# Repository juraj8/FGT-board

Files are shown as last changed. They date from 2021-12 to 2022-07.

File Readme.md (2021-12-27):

# FGT





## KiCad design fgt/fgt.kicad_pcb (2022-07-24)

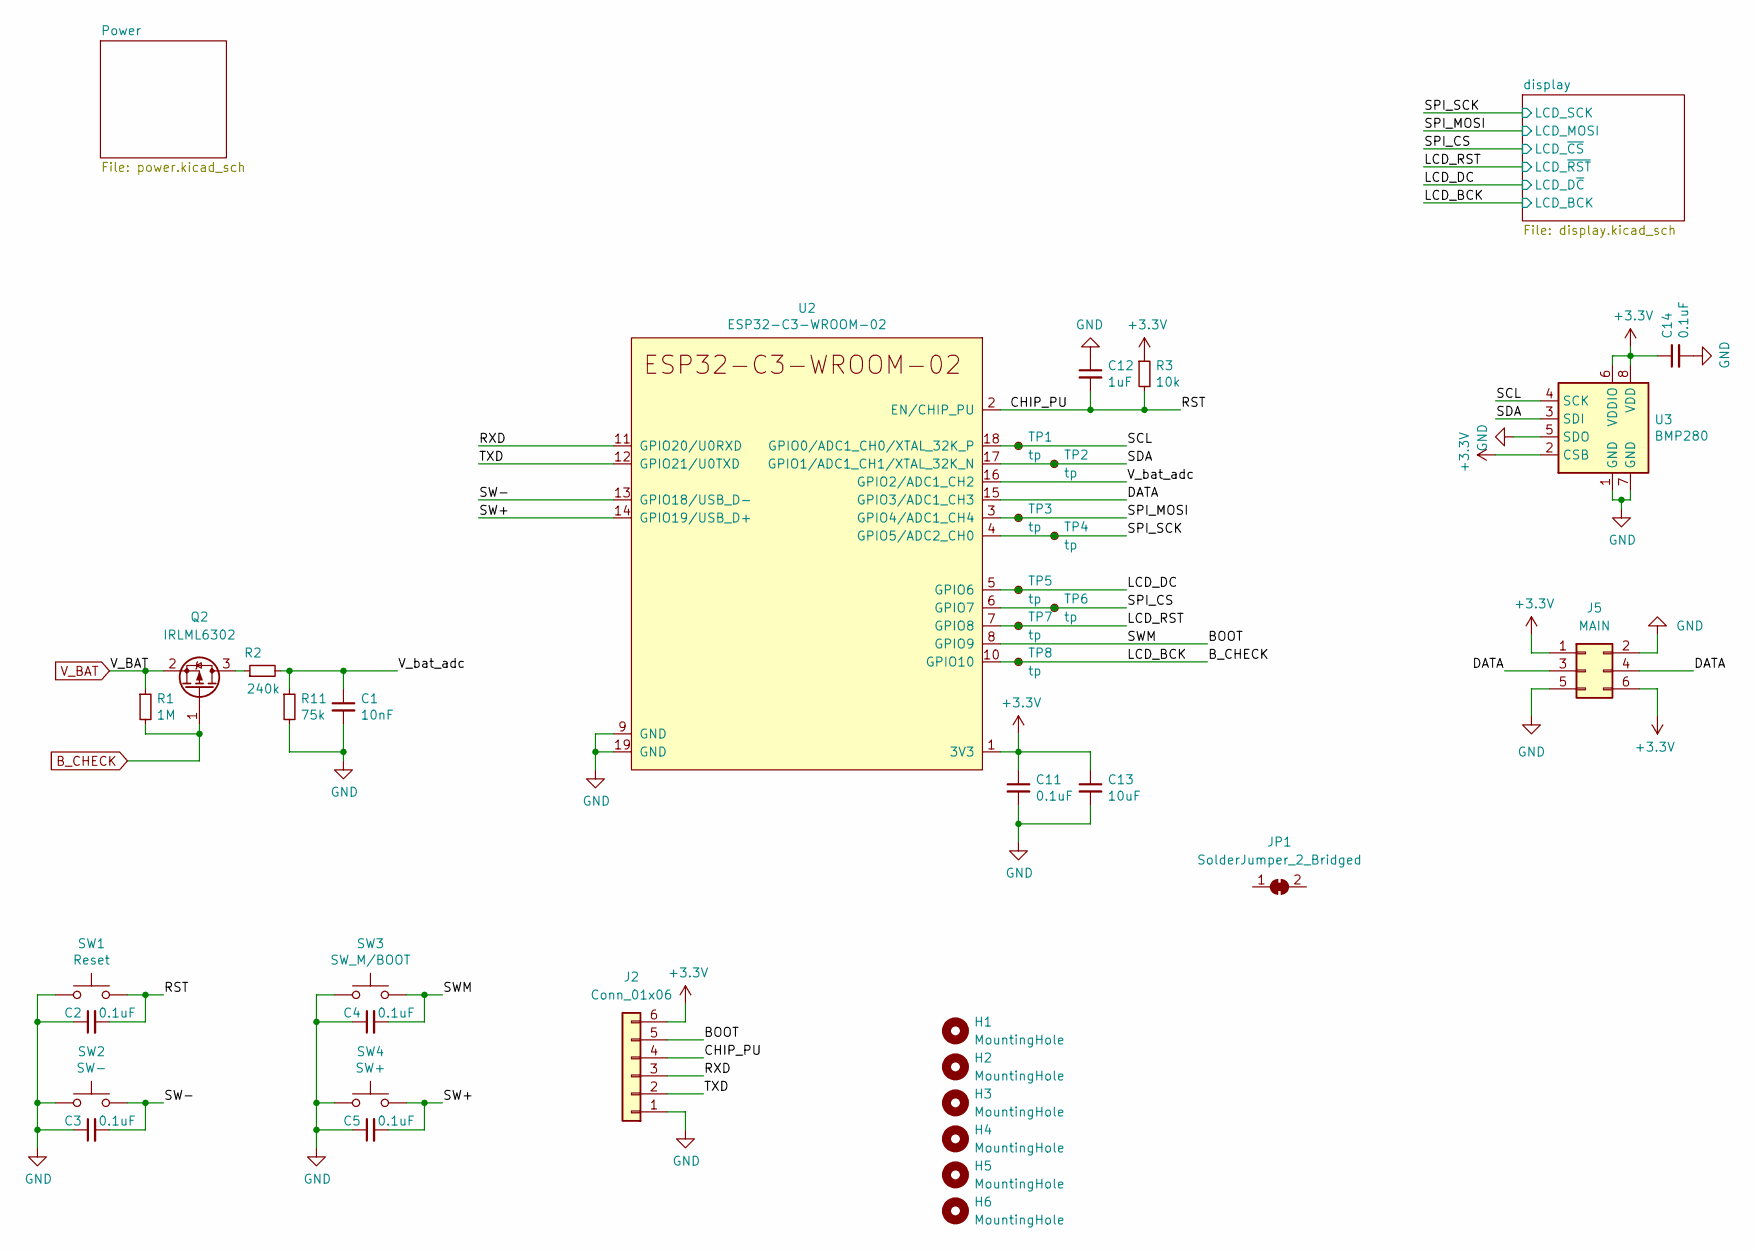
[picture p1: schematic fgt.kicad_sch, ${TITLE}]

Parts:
C1: 10nF; C_0805_2012Metric
C2, C3, C4, C5: 0.1uF; C_0805_2012Metric
C11, C14: 0.1uF; C_0603_1608Metric
C12: 1uF; C_0603_1608Metric
C13: 10uF; C_0805_2012Metric
H1, H2, H3, H4, H5, H6: MountingHole; MountingHole_3.2mm_M3_DIN965
J2: Conn_01x06; PinHeader_1x06_P2.54mm_Vertical
J5: MAIN; IDC-Header_2x03_P2.54mm_Vertical
JP1: SolderJumper_2_Bridged; SolderJumper-2_P1.3mm_Bridged_RoundedPad1.0x1.5mm
Q2: IRLML6302; SOT-23
R1: 1M; R_0805_2012Metric
R2: 240k; R_0805_2012Metric
R3: 10k; R_0805_2012Metric
R11: 75k; R_0805_2012Metric
SW1: Reset; SW_SPST_SKQG_WithStem
SW2: SW-; SW_SPST_SKQG_WithStem
SW3: SW_M/BOOT; SW_SPST_SKQG_WithStem
SW4: SW+; SW_SPST_SKQG_WithStem
TP1, TP2, TP3, TP4, TP5, TP6, TP7, TP8: tp; TestPoint_Pad_D1.0mm
U2: ESP32-C3-WROOM-02
U3: BMP280; Bosch_LGA-8_2x2.5mm_P0.65mm_ClockwisePinNumbering

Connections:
+3V3: C11.1, C13.1, C14.1, J2.6, J5.1, J5.6, R3.1, U2.1 (3V3), U3.2 (CSB), U3.6 (VDDIO), U3.8 (VDD); also elsewhere on the board
/CHIP_PU: C2.2, C12.2, J2.4, R3.2, SW1.2, U2.2 (EN/CHIP_PU)
/DATA: J5.3, J5.4, U2.15 (GPIO3/ADC1_CH3)
/LCD_DC: TP5.1, U2.5 (GPIO6); also elsewhere on the board
/LCD_RST: TP7.1, U2.7 (GPIO8); also elsewhere on the board
/RXD: J2.3, U2.11 (GPIO20/U0RXD)
/SCL: TP1.1, U2.18 (GPIO0/ADC1_CH0/XTAL_32K_P), U3.4 (SCK)
/SDA: TP2.1, U2.17 (GPIO1/ADC1_CH1/XTAL_32K_N), U3.3 (SDI)
/SPI_CS: TP6.1, U2.6 (GPIO7); also elsewhere on the board
/SPI_MOSI: TP3.1, U2.3 (GPIO4/ADC1_CH4); also elsewhere on the board
/SPI_SCK: TP4.1, U2.4 (GPIO5/ADC2_CH0); also elsewhere on the board
/SW+: C5.2, SW4.2, U2.14 (GPIO19/USB_D+)
/SW-: C3.2, SW2.2, U2.13 (GPIO18/USB_D-)
/SWM: C4.2, J2.5, SW3.2, U2.8 (GPIO9)
/TXD: J2.2, U2.12 (GPIO21/U0TXD)
/V_bat_adc: C1.1, R2.2, R11.1, U2.16 (GPIO2/ADC1_CH2)
B_CHECK: Q2.1 (G), R1.2, TP8.1, U2.10 (GPIO10); also elsewhere on the board
GND: C1.2, C2.1, C3.1, C4.1, C5.1, C11.2, C12.1, C13.2, C14.2, J2.1, J5.2, J5.5, R11.2, SW1.1, SW2.1, SW3.1, SW4.1, U2.9 (GND), U2.19 (GND), U3.1 (GND), U3.5 (SDO), U3.7 (GND); also elsewhere on the board
unnamed: Q2.3 (D), R2.1
V_BAT: Q2.2 (S), R1.1; also elsewhere on the board

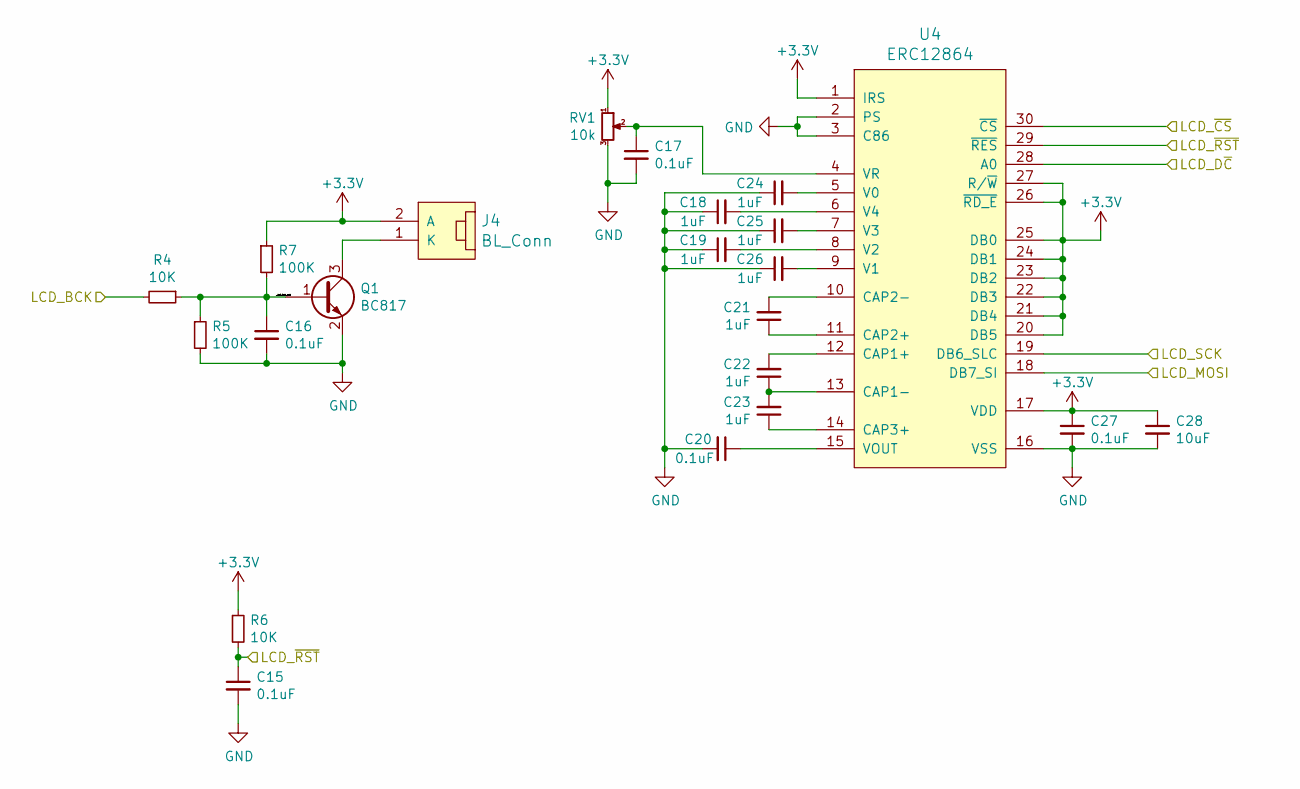
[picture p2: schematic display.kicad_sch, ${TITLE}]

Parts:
C15, C16, C17, C20, C27: 0.1uF; C_0603_1608Metric
C18, C19, C21, C22, C23, C24, C25, C26: 1uF; C_0603_1608Metric
C28: 10uF; C_0805_2012Metric
J4: BL_Conn; ER-CON2.0-2P-SMD
Q1: BC817; SOT-23
R4, R6: 10K; R_0805_2012Metric
R5, R7: 100K; R_0805_2012Metric
RV1: 10k; Potentiometer_Vishay_TS53YJ_Vertical
U4: ERC12864; ER-CON30HB-1

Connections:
+3V3: C27.1, C28.1, J4.2 (A), R6.1, R7.1, RV1.1, U4.1 (IRS), U4.17 (VDD), U4.20 (DB5), U4.21 (DB4), U4.22 (DB3), U4.23 (DB2), U4.24 (DB1), U4.25 (DB0), U4.26 (~RD_E), U4.27 (R/~W); also elsewhere on the board
/LCD_DC: U4.28 (A0); also elsewhere on the board
/LCD_RST: C15.1, R6.2, U4.29 (~RES); also elsewhere on the board
/SPI_CS: U4.30 (~CS); also elsewhere on the board
/SPI_MOSI: U4.18 (DB7_SI); also elsewhere on the board
/SPI_SCK: U4.19 (DB6_SLC); also elsewhere on the board
/display/_lcd_bck_cnt: C16.1, Q1.1 (B), R4.1, R5.1, R7.2
B_CHECK: R4.2; also elsewhere on the board
GND: C15.2, C16.2, C17.2, C18.1, C19.1, C20.2, C24.1, C25.1, C26.1, C27.2, C28.2, Q1.2 (E), R5.2, RV1.3, U4.2 (PS), U4.3 (C86), U4.16 (VSS); also elsewhere on the board
unnamed: C17.1, RV1.2, U4.4 (VR)
unnamed: C18.2, U4.6 (V4)
unnamed: C19.2, U4.8 (V2)
unnamed: C20.1, U4.15 (VOUT)
unnamed: C21.1, U4.11 (CAP2+)
unnamed: C21.2, U4.10 (CAP2-)
unnamed: C22.1, C23.2, U4.13 (CAP1-)
unnamed: C22.2, U4.12 (CAP1+)
unnamed: C23.1, U4.14 (CAP3+)
unnamed: C24.2, U4.5 (V0)
unnamed: C25.2, U4.7 (V3)
unnamed: C26.2, U4.9 (V1)
unnamed: J4.1 (K), Q1.3 (C)

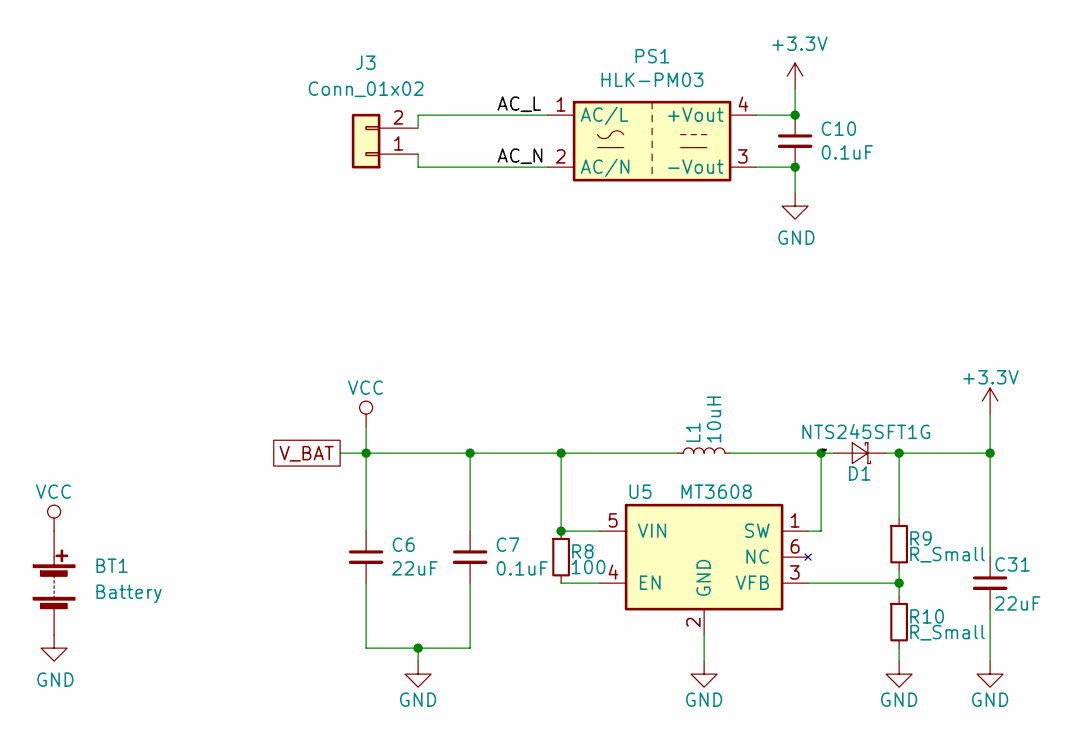
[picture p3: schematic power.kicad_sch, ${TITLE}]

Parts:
BT1: Battery; ER-CON2.0-2P-SMD
C6, C31: 22uF; C_0805_2012Metric
C7, C10: 0.1uF; C_0805_2012Metric
D1: NTS245SFT1G; D_SOD-123
J3: Conn_01x02; PhoenixContact_MSTBVA_2,5_2-G-5,08_1x02_P5.08mm_Vertical
L1: 10uH; L_1008_2520Metric
PS1: HLK-PM03; Converter_ACDC_HiLink_HLK-PMxx
R8: 100; R_0805_2012Metric
R9, R10: R_Small; R_0805_2012Metric
U5: MT3608; SOT-23-6

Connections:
+3V3: C10.1, C31.1, D1.1 (K), PS1.4 (+Vout), R9.1; also elsewhere on the board
/Power/AC_L: J3.2, PS1.1 (AC/L)
/Power/AC_N: J3.1, PS1.2 (AC/N)
/Power/sw: D1.2 (A), L1.2, U5.1 (SW)
GND: BT1.2 (-), C6.2, C7.2, C10.2, C31.2, PS1.3 (-Vout), R10.2, U5.2 (GND); also elsewhere on the board
unnamed: R9.2, R10.1, U5.3 (VFB)
unnamed: R8.2, U5.4 (EN)
V_BAT: BT1.1 (+), C6.1, C7.1, L1.1, R8.1, U5.5 (VIN); also elsewhere on the board

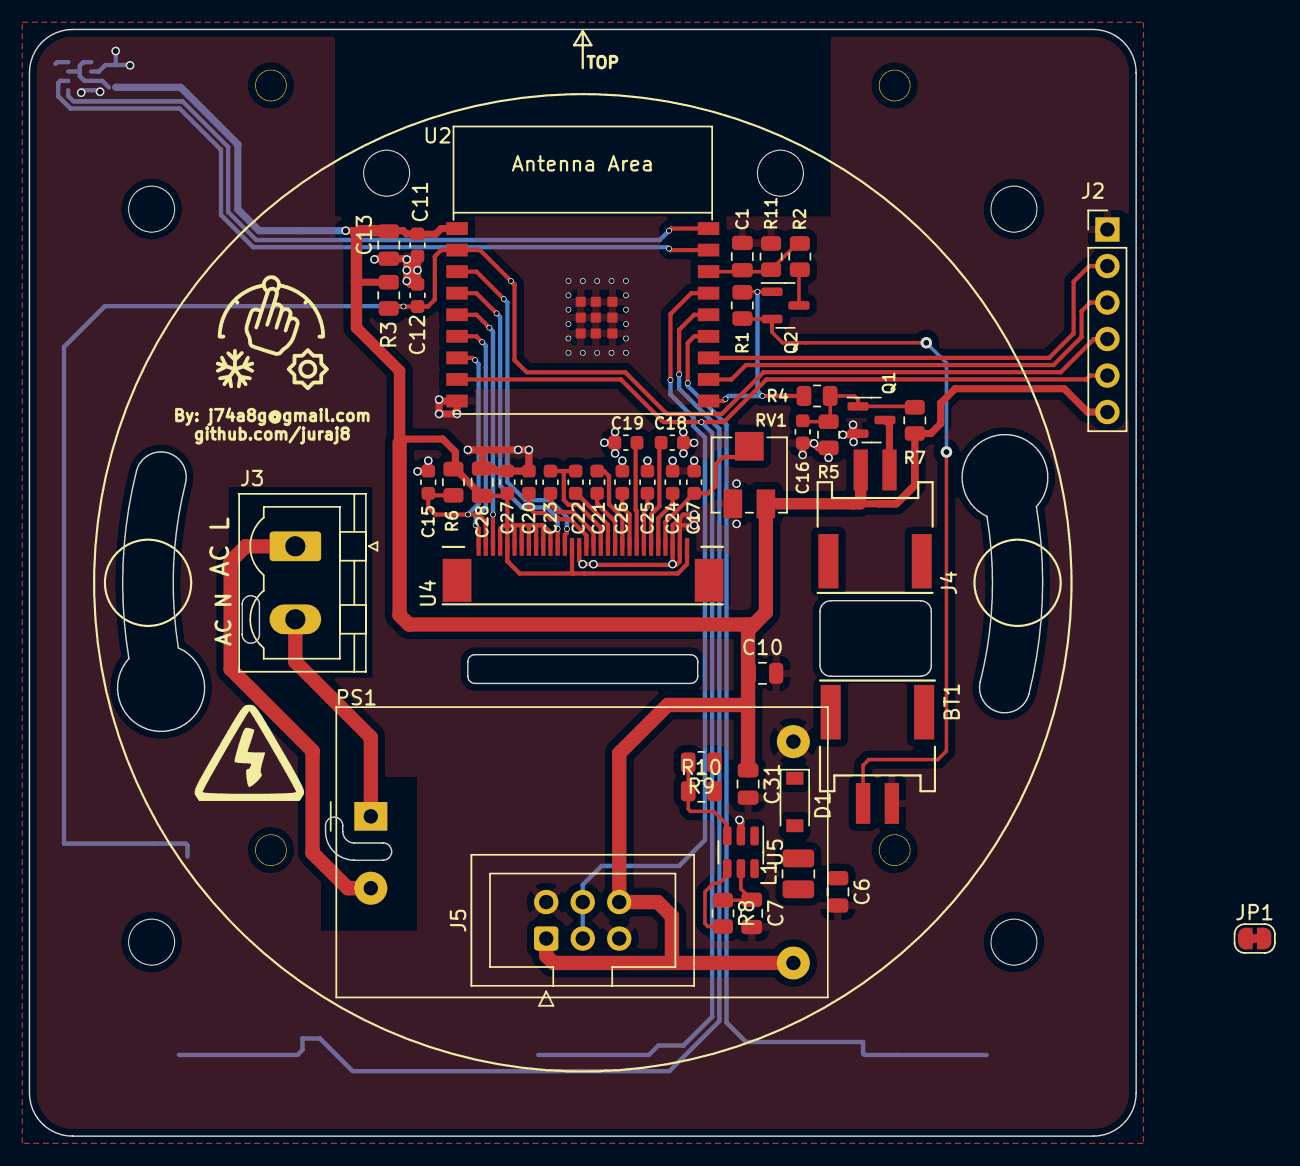
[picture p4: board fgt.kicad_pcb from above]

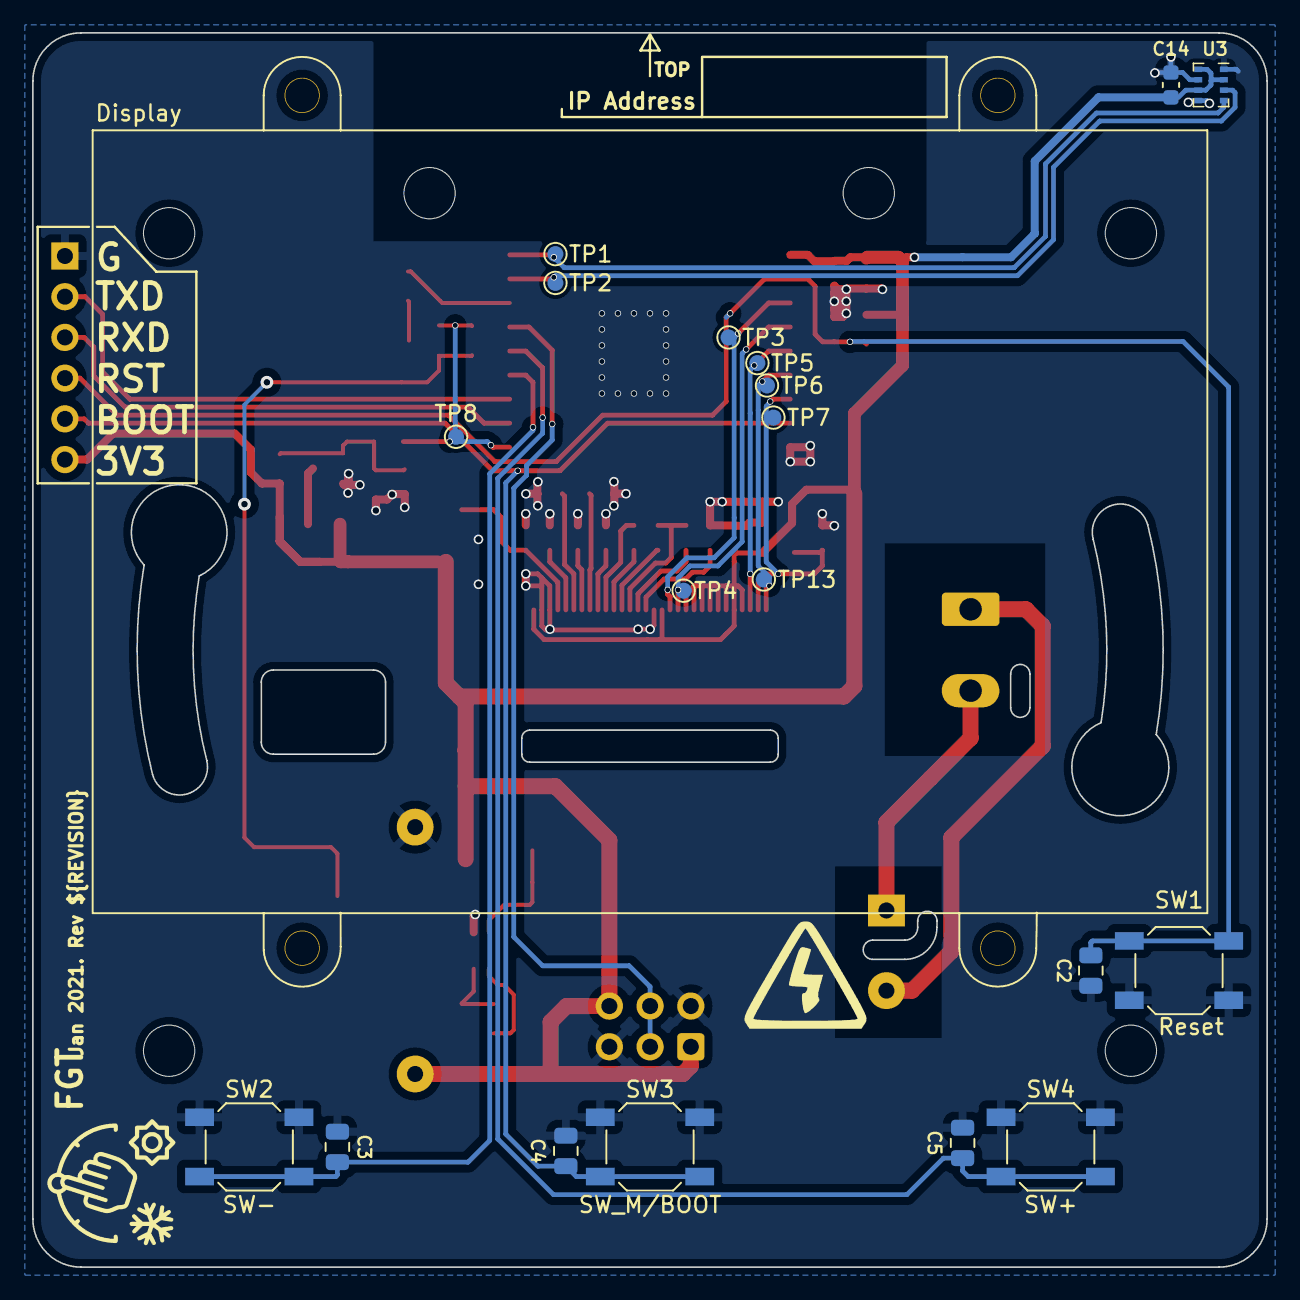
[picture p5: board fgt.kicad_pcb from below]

Board: 2 copper layers, 77.0 x 77.0 mm, 74 parts (20 on the bottom side), 39 nets.

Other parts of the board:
Display: ER-DISP
TP13: tp; TestPoint_Pad_D1.0mm

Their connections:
/SPI_CS: TP13.1; also elsewhere on the board

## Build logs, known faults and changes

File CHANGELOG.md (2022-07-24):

# Changelog

# v1.5.0 (24.07.2022)

- Removed USB port.
- Added step-up converter.
- Added battery voltage measurment.

# v1.4.0 (24.01.2022)

- First production ready pcb's.
- Added test points.
- Fix solder mask.

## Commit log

2021-12-28 Almost finished layout
    [display.kicad_sch, display.sch, feelgood.kicad_pcb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]
2022-01-01 placing locating holes
    [display.kicad_sch, fgt.kicad_pcb, fgt.kicad_sch]
2022-01-02 layout done v1.0.0
    [display.kicad_sch, fgt.kicad_pcb, fgt.kicad_sch]
2022-01-04 retouch board layout v1.1.0
    [display.kicad_sch, fgt.kicad_pcb, fgt.kicad_sch]
2022-01-04 DRC done
    [display.kicad_sch, fgt.kicad_pcb, fgt.kicad_sch]
2022-01-24 Release v1.4.0 - added testpoints - fix solder mask - size down pcb
    [display.kicad_sch, display.sch, fgt.kicad_pcb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]
2022-07-24 Release v1.5.0 - See changelog for changes.
    [display.kicad_sch, fgt.kicad_pcb, fgt.kicad_sch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]
